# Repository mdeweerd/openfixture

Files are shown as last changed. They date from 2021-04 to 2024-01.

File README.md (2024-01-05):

# OpenFixture





## Goal

The motivation of OpenFixture was to make a parametric fixturing system
that could take fully generated inputs from kicad and produce a test
fixture with minimal effort. The easiest way to use it is through the kicad
python scripting interface.

The project has been extended with Test PCB Schematic generation - you may
want to generate only that without building the proposed fixture.

## Parameters

For most projects (if using the standard BOM) the only parameters you'll
need to set are mat_th and pcb_th. Something like the following should be
sufficient:

```
usage: GenFixture.py [-h] --board BOARD --mat_th MAT_TH --out OUT
                     [--pcb_th PCB_TH] [--pcb_h PCB_H] [--screw_len SCREW_LEN]
                     [--screw_d SCREW_D] [--layer LAYER] [--flayer FLAYER]
                     [--ilayer ILAYER] [--rev REV] [--pogo_d POGO_D]
                     [--washer_th WASHER_TH] [--nut_f2f NUT_F2F]
                     [--nut_c2c NUT_C2C] [--nut_th NUT_TH] [--pivot_d PIVOT_D]
                     [--border BORDER] [--render] [--kicad]
                     [--annular ANNULAR] [--logo LOGO] [--logo-w LOGO_W]
                     [--logo-h LOGO_H] [--pins PINS]
                     [--exclude-size EXCLUDE_SIZE]

optional arguments:
  -h, --help            show this help message and exit
  --board BOARD         <board_name.kicad_pcb>
  --mat_th MAT_TH       material thickness (mm)
  --out OUT             output directory
  --pcb_th PCB_TH       pcb thickness (mm)
  --pcb_h PCB_H         pcb component height (mm)
  --screw_len SCREW_LEN
                        Assembly screw thread length (default = 16mm)
  --screw_d SCREW_D     Assembly screw diameter (default=3mm)
  --layer LAYER         F.Cu | B.Cu
  --flayer FLAYER       Eco1.User | Eco2.User
  --ilayer ILAYER       Eco1.User | Eco2.User
  --rev REV             Override revision
  --pogo_d POGO_D       Pogo hole diameter (default=1.22mm)
  --washer_th WASHER_TH
                        Washer thickness for hinge
  --nut_f2f NUT_F2F     hex nut flat to flat (mm)
  --nut_c2c NUT_C2C     hex nut corner to corner (mm)
  --nut_th NUT_TH       hex nut thickness (mm)
  --pivot_d PIVOT_D     Pivot diameter (mm)
  --border BORDER       Board (ledge) under pcb (mm)
  --render              Generate a 3d render of the final fixture
  --kicad               Generate a KiCad project
  --annular ANNULAR     Annular ring width for PADS on PCB
  --logo LOGO           Override logo
  --logo-w LOGO_W       Set logo width, mm
  --logo-h LOGO_H       Set logo height, mm
  --pins PINS           Extra pins to include (THT/SMD) REF-PINNBR - comma
                        separated
  --exclude-size EXCLUDE_SIZE
                        Module refs to exclude from board size - comma
                        separated
```

The resulting output is:

- A 3D model of the test fixture for visualization (optional, with
  '--render')
- 2D DXF files that can be directly lasercut for assembly (several
  organisations)
- A kicad project for a test board (optional)

## Requirements

- Setup your path to run KiCad's python (or a python with pcbnew).
- You may need to install some modules.\
  Either to your personal directory
  (example for ezdxf module, required for KiCad
  generation):\
  `pip install --user ezdxf`\
  Either
  globally:\
  `pip install ezdxf`

## Recommended workflow for KiCad

1. Clone this repo if you haven't already
2. Setup a project specific bash script (use genfixture.sh as an example),
   and/or add a `fixture.conf` file to your project.
3. Enter board specific info, fixture hardware, material thickness, etc.
4. Whenever the layout changes call ./genfixture.sh (from repo) and pass
   path to .kicad_pcb file.
5. Fixture will be generated in $OUTPUT folder.

## Helper script

`genfixture.sh` is a helper script that you can call with just the path to
the PROJET.kicad_pcb file. You can add more options which will be appended
to the call to `GenFixture.py`.

On windows, that script can be used under cygwin. The `cygwin.setpath`
include script shows how you can set the system paths.

`genfixture.sh` also checks the directory where the project file is located
for a `fixture.conf` configuration file and includes the contents of that
file as a bash include script.

## Hints

- Examine the `genfixture.sh` helper script to learn about option.
- If you want smaller pogo pin holes for the test fixture than the PCB,
  perform multiple generations with different parameters.

## KiCAD Test Schematic & Board Generation

The `generate_kicad.py` script is called from `GenFixture.py` when the
`--kicad` option is added.

This generates a schematic sheet with the test pins connected to global
netnames corresponding to the netnames on the original schematic. It also
generates a board that puts the test pins in the right locations.

You can edit the board to change the EDGES to make a bigger board for
instance. You can edit the schematic to add other connectors for test
purposes or electronics for test purposes.

The best method would be the use of hierarchical sheets so that the POGOPIN
schematic can be regenerated.

## Hardware

- All that is needed is 14xM3 (14mm+) screws, 14xM3 hex nuts, and lasercut
  parts
- Nylon bushings in the main pivot with m3 screws for a smoother joint can
  be used, but this is optional

## Documentation

https://tinylabs.io/openfixture

## BOM

Material needed to build the Fixture: https://tinylabs.io/openfixture-bom

- 15 M3 nuts
- 15 M3 hex nuts
- Pogo sockets
- Pogo pins
- Glue

Pogo pins come in different sizes, and are composed of a socket and a pin.
There are R100 sockets, as well as R50 sockets and other sized. The drill
sizes change accordingly. You can find them from different sources. You can
find several source by looking for `R100-2S` or `R50-2W7`

- DirtyPCBs proposes R100-\* type sockets. Make sure that you use the
  corresponding P100-\* pins
  https://dirtypcbs.com/store/designer/details/ian/12/dirty-pogo-pins
- Aliexpress, Alibaba, Amazon, CDiscount are marketplaces where you can
  find many other vendors.

## STEP export

A standalone scad file is generated.\
Copy the logos and font to the
directory where the generated scad file is located. Or, copy the SCAD file
to the script directory. You can perform
`./convert_shape.py <SCADFILE> out.step` to convert to STEP for instance.

There is a bug in FreeCad 0.19 that prevents generation (on Windows)

## STL export

A standalone scad file is generated.\
Copy the logos and font to the
directory where the generated scad file is located. Or, copy the SCAD file
to the script directory. You can perform
`openscad --render -o out.stl <SCADFILE>` to convert to STL for instance.

## Testpoint validation

To verify that all your testpoints are within the PCB area, you can check
that no checkpoint appears in the `*-validate.dxf` file.

## Assembly

More info including detailed assembly instructions at
https://tinylabs.io/openfixture-assembly

## Dependencies

- Newer version of openscad >= 2015.03-1
- kicad or other EDA software. Please email me if you have instructions for
  other packages so I can add them.

## Known Issues

- When loading the fonts file a new small window opens in Ubuntu. Seems
  innocuous but still annoying \[Only seen on ubuntu 14.04\]
- STEP generation with FreeCAD is not entirely functional

## License

Creative Commons (CC BY-SA 4.0)

## Contributors

- Elliot Buller - Tiny Labs Inc
- Mario DE WEERD - Ynamics

(?) Please email with any pull requests or new feature requests
elliot@tinylabs.io

## Resources

KiCAD PCB generation script initiated from
https://github.com/jaseg/pogojig.git

## Work in progress / possible features

- The generation of a hierchical sheet is work in progress
- 3D models of test sockets and pins are generated. They must be verified
  and could be integrated as KiCad components.
- Mechanical holes should also be "exported" to the KiCad project to allow
  adding guides.
- Add a filter to exclude specific pins.
- KiCad integration (in a distant future)

# Old stuff

## KiCAD export

https://tinylabs.io/openfixture-kicad-export

Getting the test pins from the kicad schematic is integrated in this
project.

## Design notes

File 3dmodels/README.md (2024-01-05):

# Pin 3D Models

Most Pogo Pin models are generated using the `create-steps.sh` script that
calls upon the `pogopins.scad` script. At this time they are not verified
against physical pins so measures may be incorrect.

There are other 3D Models available on the Web that are not provided in
this repository. They can be downloaded from the following sources and are
subject to their respective licences.

- https://grabcad.com/library/pogo-pins-1

# Actual Pogo-pins

- After inserting the P50-J1 pin in the R50-2W7 socket, the total extended
  length is about 21mm. The non moving part of the pin enters entirely in
  the socket. The moving part of the pin extends about 3.5mm from the end
  and retracts fully when pushed.\
  The R-50-2W7 is 13mm in length from the
  pin entry up to the retraction before the wire.\
  The Wire entry up to the
  retraction is 4.5mm, the total length of the socket is 17.5mm The
  extrusion on the R50-2W7 socket is 2.5mm from the edge

# TODO

- Add more pin heads;
- Also generate "compressed" versions of the PIN Models (i.e., versions
  where the pin extends less from the socket because it is compressed
  against a board).

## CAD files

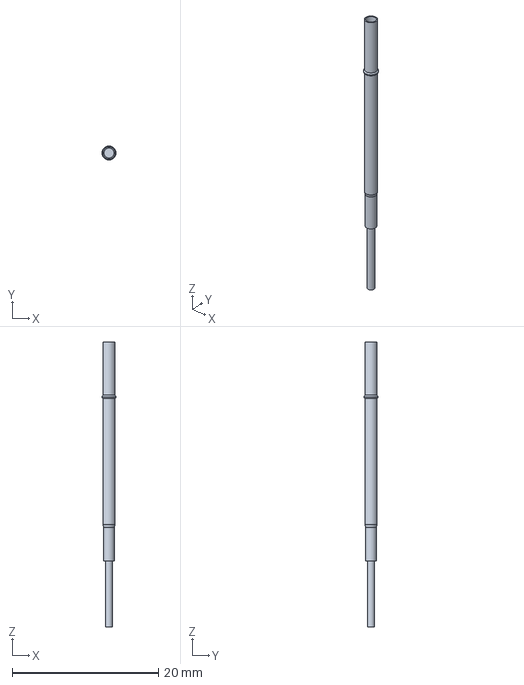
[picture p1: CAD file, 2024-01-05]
3dmodels/tmp.step
1.93 x 1.93 x 39.0 mm

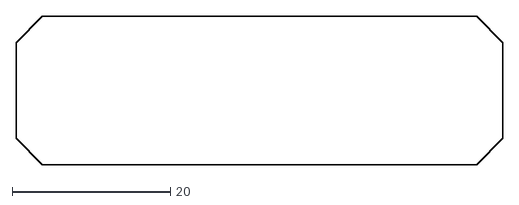
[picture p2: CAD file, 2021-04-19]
demo_result/yardstickone-validate.dxf
61.5 x 18.7

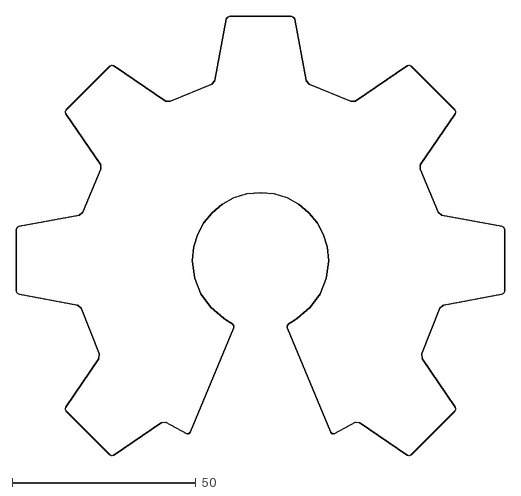
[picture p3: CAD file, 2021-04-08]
osh_logo.dxf
132.9 x 119.6

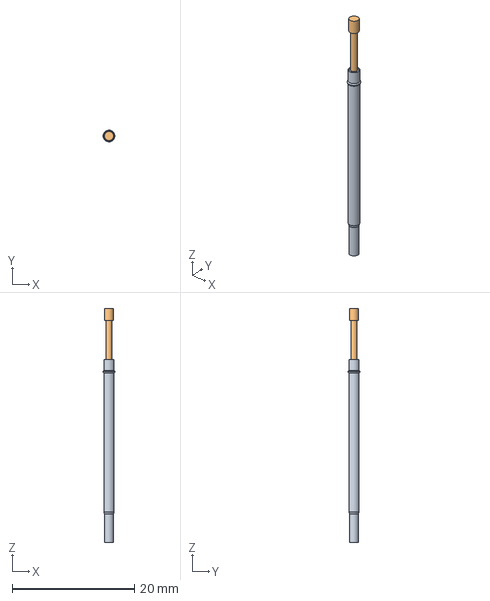
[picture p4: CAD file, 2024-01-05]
3dmodels/R100-2S-P100-G2.step
1.93 x 1.93 x 38.4 mm

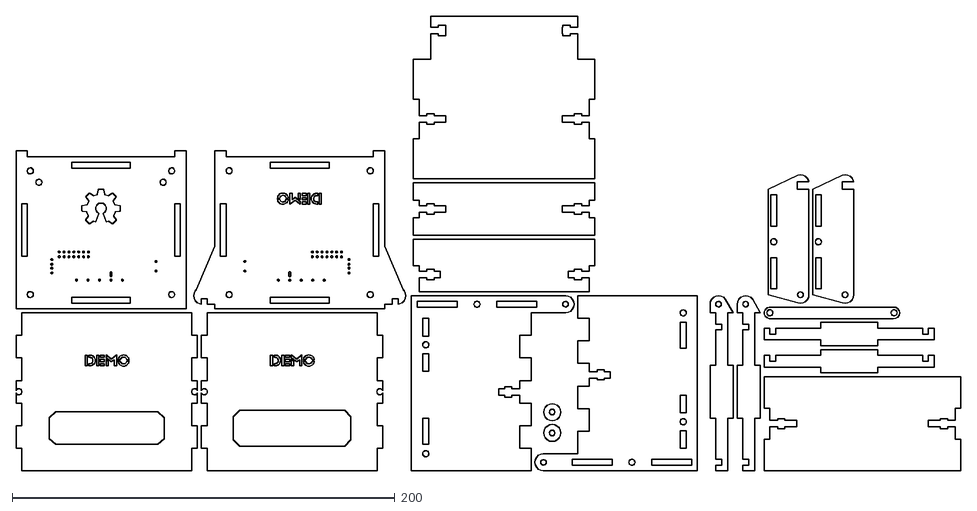
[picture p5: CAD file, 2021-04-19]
demo_result/yardstickone-v2-fixture.dxf
494.0 x 237.7

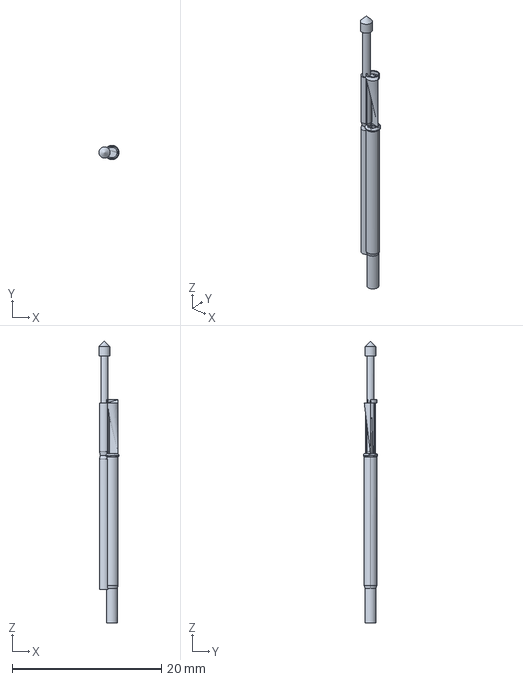
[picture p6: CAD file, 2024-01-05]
3dmodels/test.step
2.71 x 1.93 x 37.9 mm

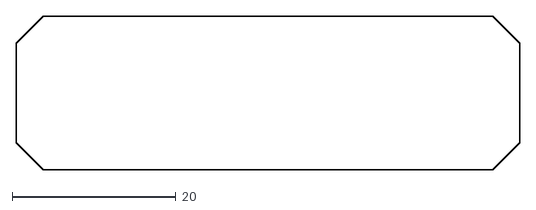
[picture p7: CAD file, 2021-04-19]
demo_result/yardstickone-outline.dxf
61.5 x 18.7

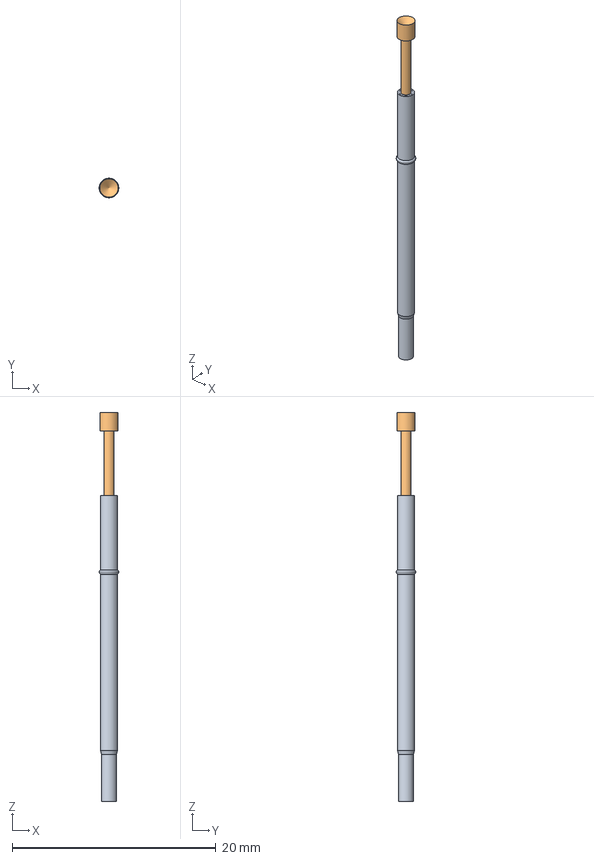
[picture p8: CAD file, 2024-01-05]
3dmodels/R100-4S-P100-A3.step
1.93 x 1.93 x 38.1 mm

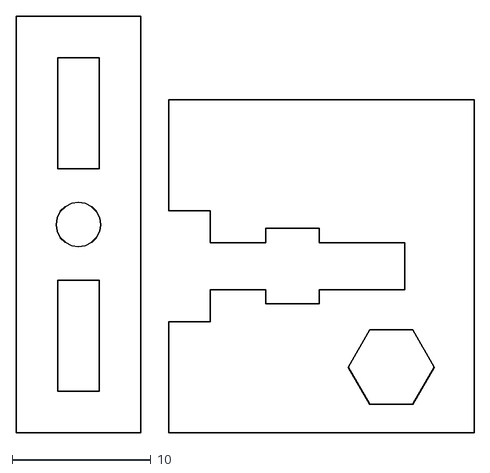
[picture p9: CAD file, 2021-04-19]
demo_result/yardstickone-test.dxf
33.0 x 30.0

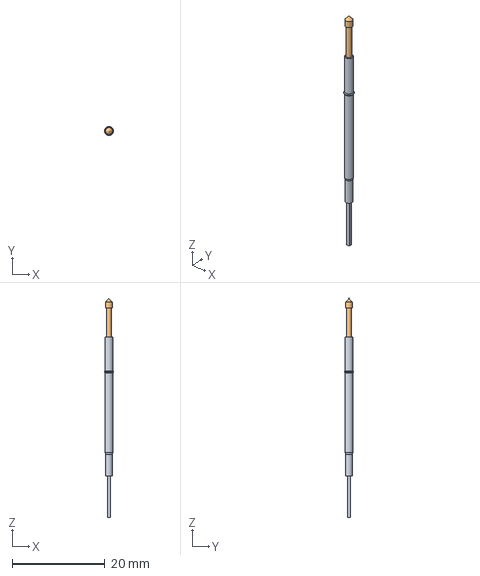
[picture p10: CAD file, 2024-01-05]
3dmodels/R100-4W-P100-E2.step
1.93 x 1.93 x 47.4 mm

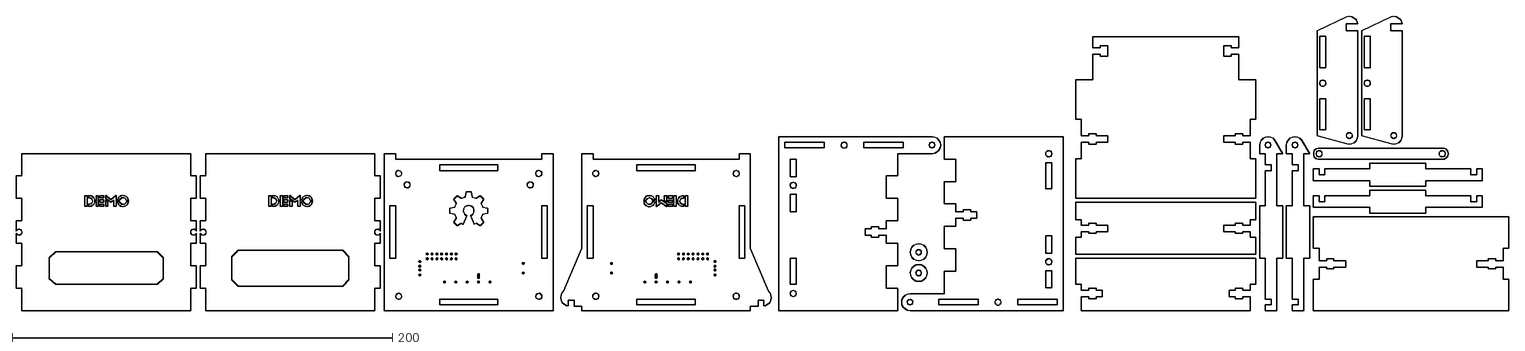
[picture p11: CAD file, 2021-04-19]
demo_result/yardstickone-fixture.dxf
785.6 x 154.8

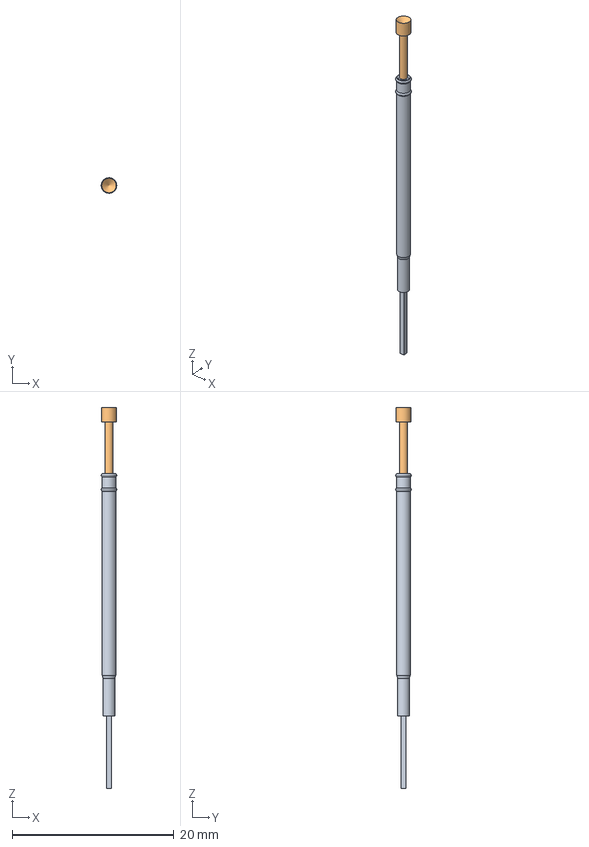
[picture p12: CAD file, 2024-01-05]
3dmodels/R100-1W-P100-A3.step
1.93 x 1.93 x 47.1 mm

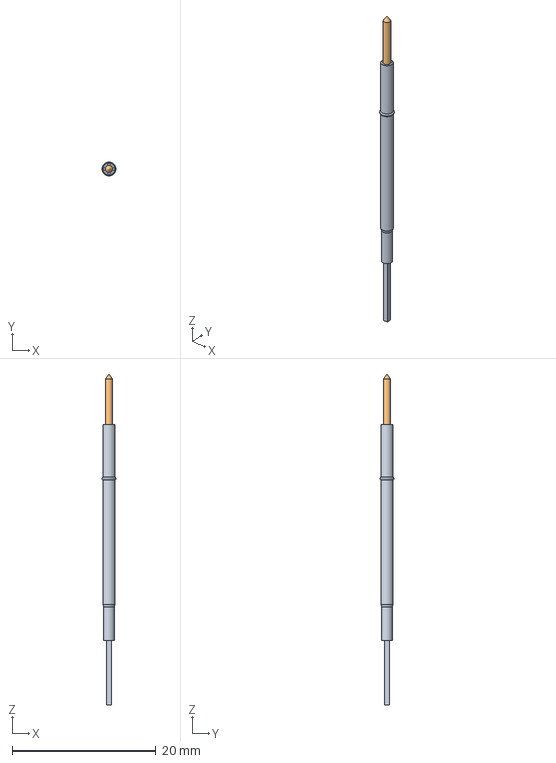
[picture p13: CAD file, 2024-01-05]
3dmodels/R100-4W-P100-B1.step
1.93 x 1.93 x 46.1 mm

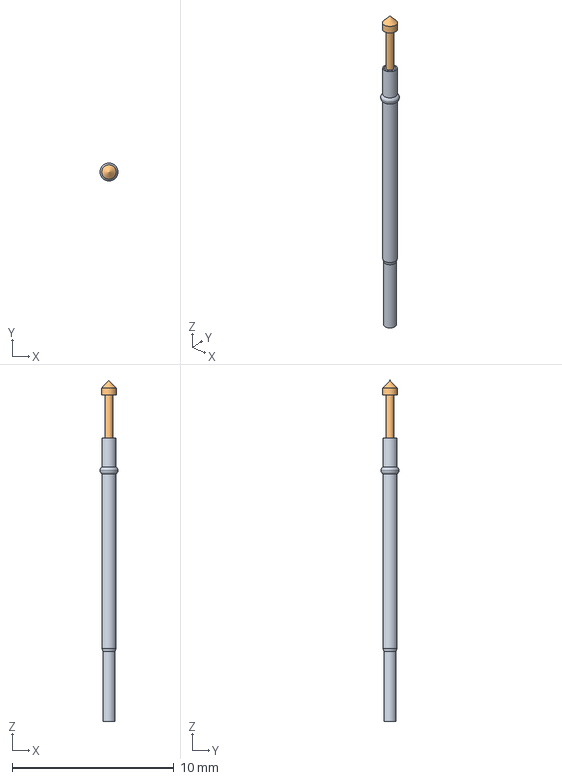
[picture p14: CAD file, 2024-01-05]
3dmodels/R50-2W7-P50-E2.step
1.11 x 1.11 x 21.0 mm

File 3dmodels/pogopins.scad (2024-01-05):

/**
 * Author: Mario DE WEERD - https://github.com/mdeweerd
 *
 * License: CC-BY-SA
 *   See: by-sa-4.0.md or https://creativecommons.org/licenses/by-nc-sa/4.0/legalcode
 */
// This script generates POGOPIN models.
// Note: The result has not been compared with physical pins yet.
gold="#ffd700";

pin_type="B1";
//socket_type="1W";
//socket_type="2W";
socket_type="2W7";
//socket_type="4W";
//socket_type="5W";
//socket_type="2S";
//socket_type="4S";
//socket_type="4VW";
//socket_type="3T";
//family="R100";
family="R50";

pin_corps_d=(family=="R100")?1.36:
              (
               (family=="R50")?0.68:
                  -1
              );
pin_notch_off=(family=="R100")?7:
              (
               (family=="R50")?5: // Estimate
                  -1
              );
pin_corps_len=(family=="R100")?25:
              (
               (family=="R50")?13:
                  -1
              );


pin_head_diameter=((family=="R100")?1:((family=="R50")?0.48:-1));
pin_head_margin=0.02;
pin_corps_empty_diameter=pin_head_diameter+pin_head_margin;

pin_center_barrel_offset=10;
pin_center_barrel_ext_len=
          family=="R100"?6.35:
          (family=="R50"?2.65 // 2.65=average? - 3.5 measured
          :-1);
pin_center_barrel_len=pin_corps_len-pin_center_barrel_offset+pin_center_barrel_ext_len;

module pin_head() {

  // Pin outer cylinder
  difference() {
    cylinder(h=pin_corps_len,d=pin_corps_d,$fa=1,$fs=0.01,$fn=100);
    union() {
      // Remove center of cylinder
      translate([0,0,1]) // Bottom of 1mm
        cylinder(h=pin_corps_len,d=pin_corps_empty_diameter,$fa=1,$fs=0.01,$fn=100);
      if(0) // No notch was observed on the P50 pin type, disabling this.
      // Create "notch" in cylinder
      translate([0,0,pin_corps_len-pin_notch_off])
        difference() {
          translate([0,0,-0.5])
            cylinder(h=1,d=pin_corps_d,$fa=1,$fs=0.01,$fn=100);
          union() {
            cylinder(h=0.5,d2=pin_corps_d,d1=pin_corps_d*.85,$fa=1,$fs=0.01,$fn=100);
            mirror([0,0,1])
              cylinder(h=0.5,d2=pin_corps_d,d1=pin_corps_d*.85,$fa=1,$fs=0.01,$fn=100);
          }
        }
    }
  }


  translate([0,0,pin_center_barrel_offset])
    cylinder(h=pin_center_barrel_len,d=pin_head_diameter,$fa=1,$fs=0.01,$fn=100,center=false);

  pin_top_offset=pin_center_barrel_offset+pin_center_barrel_len;

  pin_top_diam=
    (family=="R100")?(
     (pin_type=="E2"||pin_type=="A2"||pin_type=="D2"||pin_type=="G2"||pin_type=="H2"||pin_type=="LM2"||pin_type=="Q2"||pin_type=="T2"||pin_type=="M3")
     ?1.5
    :(pin_type=="A3"||pin_type=="E3"||pin_type=="D3"||pin_type=="H3")
     ?1.8
     :(pin_type=="B1")
     ?0.99
     :(pin_type=="F1"||pin_type=="J1"||pin_type=="Q1"||pin_type=="G1")
     ?1.0
     :(pin_type=="H4")
     ?2.0
     :(pin_type=="H5")
     ?2.5
     :(pin_type=="H6")
     ?3.0
     :-1) // Invalid
   :
    (family=="R50")?
     (
      (pin_type=="E2"||pin_type=="A2"||pin_type=="D2"||pin_type=="E2"||pin_type=="G2"||pin_type=="H2"||pin_type=="LM2"||pin_type=="Q2"||pin_type=="T2")
     ?0.9 // 2
     :(pin_type=="B1"||pin_type=="F1"||pin_type=="F"||pin_type=="J1"||pin_type=="Q1"||pin_type=="G1")
      ?0.48 // 1
      :(pin_type=="E3"||pin_type==H3)
      ?1.20 // 3
      :(pin_type=="1D"||pin_type=="1E")
      ?0.6
     :-1 // Invalid
    ):-1;
  pin_top_h=
    (family=="R100")?(
     (pin_type=="M3")
     ?7.0
     :2.0)
    :((family=="R50")?
        ((pin_type=="B1"||pin_type=="J1"||pin_type=="Q1"||pin_type=="G1")
         ?0.7:0.9)
      :-1)
  ;

  if(pin_type=="E2"||pin_type=="E3") {
      translate([0,0,pin_top_offset])
        intersection() {
          cylinder(h=pin_top_h,d=pin_top_diam,$fa=1,$fs=0.01,$fn=100,center=false);
          // 90° cone
          cylinder(h=pin_top_h,d1=pin_top_h*2,d2=0,$fa=1,$fs=0.01,$fn=100,center=false);
        };
  } else if(pin_type=="A2"||pin_type=="A3") {
echo(pin_top_diam);
      translate([0,0,pin_top_offset])
        difference() {
          cylinder(h=pin_top_h,d=pin_top_diam,$fa=1,$fs=0.01,$fn=100,center=false);
          translate([0,0,pin_top_h+pin_top_diam/2])
            mirror([0,0,1])
              cylinder(h=pin_top_h,d1=pin_top_h*2,d2=0,$fa=1,$fs=0.01,$fn=100,center=false);
        };
  } else if(pin_type=="G2"||pin_type=="G1") {
      translate([0,0,pin_top_offset])
        cylinder(h=pin_top_h,d=pin_top_diam,$fa=1,$fs=0.01,$fn=100,center=false);
  } else if(pin_type=="B1") {
      //color("red")
      translate([0,0,pin_top_offset])
        cylinder(h=pin_top_diam*cos(45),d2=0,d1=pin_top_diam,$fa=1,$fs=0.01,$fn=100,center=false);
  }
}


  cil_top_h=(family=="R100"?25:(family=="R50"?13:-1));
  ring_mid_d=(family=="R100"?1.83:(family=="R50"?0.95:-1));
  ring_top_d=(family=="R100"?1.9:(family=="R50"?0.98:-1));
  cil_top_d=(family=="R100"?1.68:(family=="R50"?0.86:-1));
  cil_mid_h=(family=="R100"?5:(family=="R50"?4.5:-1)); // Same for R100,R50
  cil_mid_d=(family=="R100"?1.47:(family=="R50"?0.75:-1));
  cub_bot_side=0.64;
  bot_d=1;

  mid_cone_h=cil_mid_d*2;

  ring_mid_off= // Ring offset from top
    (socket_type=="1W"||socket_type=="2W"||socket_type=="2S"||socket_type=="2W7"||socket_type=="1W7"||socket_type=="2C")
       ?2 // Changed to 2 as observed on 2W7 measurement (was: 2.5)
    :(socket_type=="3T"||socket_type=="3C"||socket_type=="3S")?5
    :(socket_type=="4W"||socket_type=="4S"||socket_type=="4VW")
       ?7.5
    :(socket_type=="5W"||socket_type=="2S")
    ?10
    :-1;

  square_bot=
    (socket_type=="1W"||socket_type=="2W"||socket_type=="4W"||socket_type=="5W");
  circ_bot=(socket_type=="4VW"||socket_type=="3T");
  bot_h=(socket_type=="3T")?4.5:9;

module socket() {
  difference() {
    union() {
//color("red")
      // Top part of socket
      translate([0,0,-cil_top_h])
        cylinder(h=cil_top_h,d=cil_top_d,$fa=1,$fs=0.01,$fn=100);
      translate([0,0,-cil_top_h-cil_mid_h])
        union() {
          cylinder(h=cil_mid_h,d=cil_mid_d,$fa=1,$fs=0.01,$fn=100);
          translate([0,0,cil_mid_h-mid_cone_h])
            cylinder(h=mid_cone_h,d1=0,d2=cil_top_d,$fa=1,$fs=0.01,$fn=100);
        }
      // Bottom, depending on type
      if(square_bot) {
        translate([-cub_bot_side/2,-cub_bot_side/2,-cil_top_h-cil_mid_h-bot_h])
          cube([cub_bot_side,cub_bot_side,bot_h]);
      }
      if(circ_bot) {
        translate([0,0,-cil_top_h-cil_mid_h-bot_h])
          cylinder(d=bot_d,h=bot_h,$fa=1,$fs=0.01,$fn=100);
      }
      if(socket_type=="1W") {
        translate([0,0,-0.5/2])
          ring(d=cil_top_d+0.5/2,D=0.5);
      }
      translate([0,0,-ring_mid_off])
        ring(d=cil_top_d+0.5/2,D=0.5);
    };
    // Remove center of cylinder - allow pin to enter completely
    translate([0,0,-pin_corps_len+0.001])
      cylinder(h=pin_corps_len+pin_head_margin,d=pin_corps_d+0.02,$fa=1,$fs=0.01,$fn=100);
  }

}

module ring(D = 1, d = 10,$fn=100,center=true)
{
  rotate_extrude(angle=360)
    translate([d/2 - D/2, 0])
      circle(d=D);
}

z_zero_offset=0.1;
color(gold)
union() {
  // Combine socket and pin.
  translate([0,0,cil_top_h+z_zero_offset])
    socket();
  // The notch offset was removed as it was no observed on the physical pin.
  //translate([0,0,z_zero_offset+cil_top_h-pin_corps_len+pin_notch_off-ring_mid_off])
  // The non-moving part of the pin enters entirely in the socket
  translate([0,0,z_zero_offset+cil_top_h-pin_corps_len])
    pin_head();
}

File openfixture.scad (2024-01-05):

/**
 *  OpenFixture - The goal is to have a turnkey pcb fixturing solution
 *  as long as you have access to a laser cutter or laser cutting service.
 *
 *  The input is:
 *   1. (x, y) work area that is >= pcb size
 *   2. (x, y) coordidates of test point centers
 *   3. dxf of pcb outline aligned with (0,0) on the top left.
 *   4. Material parameters: acrylic thickness, kerf, etc
 *
 *  The output is a dxf containing all the parts (minus M3 hardware)
 *  to assemble the fixture.
 *
 *  Creative Commons Licensed  (CC BY-SA 4.0)
 *  Tiny Labs
 *  2016
 */
use <glaser-stencil-d.ttf>;
FONTNAME = "Glaser Stencil D";

//
// PCB input
//
// Test points
demo_test_points = [[23.22,25.85],[19.72,22.28],[3.95,25.77],[7.52,22.27],[13.60,13.70],[13.55,18.70],[13.55,34.90],[13.60,29.90],[44.03,101.93],[110,110],[100,100],[60,60]];
// 68.72, 121.43

test_points = demo_test_points;

// Used below to calculate distance from hinge to nearest point based on min
// contact angle... Ideally we want it as close to 90 degrees as possible
// All you have to know is look through 'y' column above and set to lowest val
tp_min_y = 13.7;

// DXF outline of pcb
pcb_outline = "./rfid_fob-outline.dxf";
osh_logo = "./osh_logo.dxf";

logo = "";

// PCB revision
rev = "rev.0";

// Should be close to actual pcb dimensions... Used for support structure only so not critical
pcb_x = 54;
pcb_y = 117.45;
pcb_support_border = 1;

pcb_max_height_component = 12.5;

logo_w = 50;
logo_h = 50;

// Work area of PCB
// Must be >= PCB size
// If you make this as big as any of the PCBs you work
// with you could then reuse the base and just swap the
// head and carriers based on the pcb you're using.
work_area_x = pcb_x;
work_area_y = pcb_y;

// Thickness of pcb
pcb_th = 1.6;  // Standard PCB size

//
// End PCB input
//

// Correction offset
// These are final adjustments relative to the board carrier.
// Usually these aren't needed but can be used to tweak alignment
tp_correction_offset_x = 0.0;
tp_correction_offset_y = 0.0;

// Default mode (for debug)
mode="3dmodel";
render=1;



// Smoothness function for circles
$fn = 15;

// All measurements in mm
// Material parameters
mat_th = 3.0;

// Kerf adjustment
kerf = 0.125;

// Space between laser parts
laser_pad = 2;

// Screw radius (we want this tight to avoid play)
// This should work for M3 hardware
// Just the threads, not including head
// Should be no less than 12
screw_thr_len = 16;
screw_d = 3.0;
screw_r = screw_d / 2;

// Uncomment to use normal M3 screw for pivot
// We need pivot_d tight for precise alignment
pivot_d = screw_d - 0.1;
// Uncomment to use bushing in pivot
//pivot_d = 5.12;
pivot_r = pivot_d / 2;

// Pivot support, 3mm on either side
pivot_support_d = pivot_d + 6;
pivot_support_r = pivot_support_d / 2;

// Metric M3 hex nut dimensions
// f2f = flat to flat
nut_od_f2f = 5.45;
nut_od_c2c = 6;
nut_th = 2.25;

// Option to add nylon washer on latching mechanism for smoother
// operation - disabled by default
washer_th = 0;
//washer_th = 1;

// Pogo pin receptable dimensions
// I use the 2 part pogos with replaceable pins. Its a lifer save when a
// pin breaks. Undersized so they can be carefully drilled out using #50
// drill bit for better precision. If you have access to a nicer laser you
// can size these exactly
pogo_r = 1.22 / 2;

// Uncompressed length from receptacle
pogo_uncompressed_length = 16;
pogo_compression = 1;

// Locking tab parameters
tab_width = 3 * mat_th;
tab_length = 4 * mat_th + washer_th;

// Stop tab
stop_tab_y = 2 * mat_th;

// HANDLE_DO_NOT_REMOVE

//
// DO NOT EDIT BELOW... unless you feel like it ;-)
//
// Calculate min distance to hinge with a constraint on
// the angle of the pogo pin when it meets compression with the board.
// a = compression
// c = active_y_offset + pivot_support_r
// cos (min_angle) = a^2 / (2ca)
min_angle = 89.5;

// Calculate active_y_back_offset
active_y_back_offset = (pow (pogo_compression, 2) / (cos (min_angle) * 2 * pogo_compression)) - pivot_support_r - tp_min_y;

// Active area parameters
active_x_offset = 2 * mat_th + nut_od_f2f + 2;
active_y_offset = 2 * mat_th + nut_od_f2f + 2;

// Head dimensions
head_x = work_area_x + 2 * active_x_offset;
head_y = work_area_y + active_y_offset + active_y_back_offset;
head_z = screw_thr_len - nut_th;

// Base dimensions
base_x = head_x + 2 * mat_th;
base_y = head_y + pivot_support_d;
//base_z = screw_thr_len + 3 * mat_th;
base_z = screw_thr_len + 3 * mat_th + (pcb_max_height_component - 12.5);
base_pivot_offset = pivot_support_r +
                    (pogo_uncompressed_length - pogo_compression) -
                    (mat_th - pcb_th);

// To account for capture nut overhang
nut_pad = (nut_od_c2c - mat_th) / 2;

// Derived latch dimensions
latch_z_offset = (base_z * (2 / 3) + base_pivot_offset - pivot_r) / 2;
support_x = base_x / 12 + 2 * mat_th;
latch_support_y = base_z * (2 / 3) + base_pivot_offset - pivot_support_r - 2 * mat_th;



if (mode == "lasercut")  lasercut ();
if (mode == "lasercut_v2")  lasercut_v2 ();
if (mode == "3dmodel") 3d_model ();
if (mode == "validate") validate_testpoints (pcb_outline);
if (mode == "testcut") testcut ();

//
// MODULES
//
module tnut_female (n, length = screw_thr_len)
{
    // How much grip material
    tnut_grip = 4;

    // Pad for screw
    pad = 0.4;
    screw_len_pad = 1;

    // Screw hole
    translate ([0, -screw_r - pad/2])
      square ([length + screw_len_pad, screw_d + pad]);

    // Make space for nut
    translate ([mat_th * n + tnut_grip, -nut_od_f2f/2])
      square ([nut_th, nut_od_f2f]);
}

module tnut_hole ()
{
    pad = 0.1;
    circle (r = screw_r + pad, $fn = 20);
}

module tng_n (length, cnt)
{
    tng_y = (length / cnt);

    translate ([0, -length / 2])
      union () {
        for (i = [0 : 2 : cnt - 1]) {
            translate ([0, i * tng_y])
              square ([mat_th, tng_y]);
        }
      };
}

module tng_p (length, cnt)
{
    tng_y = length / cnt;

    translate ([0, -length / 2])
      union () {
        for (i = [1 : 2 : cnt - 1]) {
            translate ([0, i * tng_y])
              square ([mat_th, tng_y]);
        }
      };
}

module nut_hole ()
{
    pad = 0.05;
    circle (r = nut_od_c2c/2 + pad, $fn = 6);
}

module testcut ()
{
    y = 30;
    off = 3 * mat_th + laser_pad;

    difference () {
        union () {
            square ([3 * mat_th, y]);

            translate ([off, 0])
              square ([screw_thr_len + 2 * mat_th, y - 2 * mat_th]);
        }
        // Remove tng slot
        translate ([mat_th, y/2])
          tng_n (y - 2 * mat_th, 3);

        // Remove tnut hole
        translate ([mat_th * 3/2, y/2])
          tnut_hole ();

        // Remove tng from male side
        translate ([off, y/2 - mat_th])
          tng_p (y - 2 * mat_th, 3);

        // Remove tnut
        translate ([off, y/2 - mat_th])
          tnut_female (1);

        // Remove nut hole
        translate ([off + nut_od_c2c / 2 + screw_thr_len - mat_th, nut_od_f2f / 2 + 2])
          nut_hole ();
    }
}

module head_side ()
{
    x = head_z;
    y = head_y;
    r = pivot_support_r;

    difference () {
        union () {
            hull () {
                translate ([0, y])
                  square ([x, 0.01]);

                // Add pivot point
                translate ([r, y + pivot_support_r])
                  circle (r = pivot_support_r, $fn = 20);
            };
            square ([x, y]);
        }

        // Remove pivot
        translate ([r, y + r])
          circle (r = pivot_r, $fn = 20);

        // Remove slots
        translate ([0, y / 2])
          tng_n (y, 3);
        translate ([x - mat_th, y / 2])
          tng_n (y, 3);

        // Remove lincoln log slots
        translate ([0, mat_th])
          square ([x / 2, mat_th]);
        translate ([0, y - 3 * mat_th])
          square ([x / 2, mat_th]);
    }
}

module head_front_back ()
{
    x = head_x;
    y = head_z;

    difference () {
        square ([x, y]);

        // Remove grooves
        translate ([x / 2, 0])
          rotate ([0, 0, 90])
            tng_n (x, 3);
        translate ([x / 2, y - mat_th])
          rotate ([0, 0, 90])
            tng_n (x, 3);

        // Remove assembly slots
        translate ([mat_th, y / 2])
          square ([mat_th, y / 2]);
        translate ([x - 2 * mat_th, y / 2])
          square ([mat_th, y / 2]);
    }
}

module lock_tab ()
{
    translate ([-tab_length/2, 0])
      square ([tab_length, tab_width]);
    translate ([-tab_length/2, tab_width/2])
      circle (r = tab_width / 2, $fn = 20);
    translate([0, tab_width / 2])
      polygon([[0,0], [-tab_length/2 - tab_width /2, 0], [0,tab_length * 2], [0,0]]);
}

module head_base ()
{
    nut_offset = 2 * mat_th + screw_r;

    difference () {

        union () {
            // Common base
            head_base_common ();
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

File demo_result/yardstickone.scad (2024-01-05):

/**
 *  OpenFixture - The goal is to have a turnkey pcb fixturing solution
 *  as long as you have access to a laser cutter or laser cutting service.
 *
 *  The input is:
 *   1. (x, y) work area that is >= pcb size
 *   2. (x, y) coordidates of test point centers
 *   3. dxf of pcb outline aligned with (0,0) on the top left.
 *   4. Material parameters: acrylic thickness, kerf, etc
 *
 *  The output is a dxf containing all the parts (minus M3 hardware)
 *  to assemble the fixture.
 *
 *  Creative Commons Licensed  (CC BY-SA 4.0)
 *  Tiny Labs
 *  2016
 */
use <glaser-stencil-d.ttf>;
FONTNAME = "Glaser Stencil D";

//
// PCB input
//
// Test points
demo_test_points = [[23.22,25.85],[19.72,22.28],[3.95,25.77],[7.52,22.27],[13.60,13.70],[13.55,18.70],[13.55,34.90],[13.60,29.90],[44.03,101.93],[110,110],[100,100],[60,60]];
// 68.72, 121.43

test_points = demo_test_points;

// Used below to calculate distance from hinge to nearest point based on min
// contact angle... Ideally we want it as close to 90 degrees as possible
// All you have to know is look through 'y' column above and set to lowest val
tp_min_y = 13.7;

// DXF outline of pcb
pcb_outline = "./rfid_fob-outline.dxf";
osh_logo = "./osh_logo.dxf";

logo = "";

// PCB revision
rev = "rev.0";

// Should be close to actual pcb dimensions... Used for support structure only so not critical
pcb_x = 54;
pcb_y = 117.45;
pcb_support_border = 1;

pcb_max_height_component = 12.5;

logo_w = 50;
logo_h = 50;

// Work area of PCB
// Must be >= PCB size
// If you make this as big as any of the PCBs you work
// with you could then reuse the base and just swap the
// head and carriers based on the pcb you're using.
work_area_x = pcb_x;
work_area_y = pcb_y;

// Thickness of pcb
pcb_th = 1.6;  // Standard PCB size

//
// End PCB input
//

// Correction offset
// These are final adjustments relative to the board carrier.
// Usually these aren't needed but can be used to tweak alignment
tp_correction_offset_x = 0.0;
tp_correction_offset_y = 0.0;

// Default mode (for debug)
mode="3dmodel";
render=1;



// Smothness function for circles
$fn = 15;

// All measurements in mm
// Material parameters
mat_th = 3.0;

// Kerf adjustment
kerf = 0.125;

// Space between laser parts
laser_pad = 2;

// Screw radius (we want this tight to avoid play)
// This should work for M3 hardware
// Just the threads, not including head
// Should be no less than 12
screw_thr_len = 16;
screw_d = 3.0;
screw_r = screw_d / 2;

// Uncomment to use normal M3 screw for pivot
// We need pivot_d tight for precise alignment
pivot_d = screw_d - 0.1;
// Uncomment to use bushing in pivot
//pivot_d = 5.12;
pivot_r = pivot_d / 2;

// Pivot support, 3mm on either side
pivot_support_d = pivot_d + 6;
pivot_support_r = pivot_support_d / 2;

// Metric M3 hex nut dimensions
// f2f = flat to flat
nut_od_f2f = 5.45;
nut_od_c2c = 6;
nut_th = 2.25;

// Option to add nylon washer on latching mechanism for smoother
// operation - disabled by default
washer_th = 0;
//washer_th = 1;

// Pogo pin receptable dimensions
// I use the 2 part pogos with replaceable pins. Its a lifer save when a
// pin breaks. Undersized so they can be carefully drilled out using #50
// drill bit for better precision. If you have access to a nicer laser you
// can size these exactly
pogo_r = 1.22 / 2;

// Uncompressed length from receptacle
pogo_uncompressed_length = 16;
pogo_compression = 1;

// Locking tab parameters
tab_width = 3 * mat_th;
tab_length = 4 * mat_th + washer_th;

// Stop tab
stop_tab_y = 2 * mat_th;

//
// Parameters from command line
//
pogo_r = 0.45;
logo_h = 50;
nut_od_f2f = 5.45;
test_points = [[5.25,6.04],[5.25,8.54],[5.25,10.54],[5.25,13.04],[24.38,4.59],[24.38,2.05],[21.84,4.59],[21.84,2.05],[19.30,4.59],[19.30,2.05],[16.76,4.59],[16.76,2.05],[14.22,4.59],[14.22,2.05],[11.68,4.59],[11.68,2.05],[9.14,4.59],[9.14,2.05],[59.69,12.08],[59.69,7.00],[18.18,16.82],[24.19,16.82],[30.19,16.82],[36.19,16.82],[42.18,16.82],[36.19,14.49],[36.19,12.97],[36.19,13.73],];
nut_th = 3.85;
pcb_outline = "D:\\mdeweerd\\KiCAD\\openfixture\\demo_result\\yardstickone-outline.dxf";
logo_w = 50;
pcb_support_border = 0.80;
pcb_x = 61.97;
rev = "DEMO";
tp_min_y = 2.05;
nut_od_c2c = 6.10;
screw_thr_len = 16.00;
pcb_th = 1.60;
pcb_max_height_component = 50.00;
pcb_y = 18.40;
mat_th = 3.00;
screw_d = 3.00;
border = 0.80;
washer_th = 1.00;
mode = "3dmodel";


//
// DO NOT EDIT BELOW... unless you feel like it ;-)
//
// Calculate min distance to hinge with a constraint on
// the angle of the pogo pin when it meets compression with the board.
// a = compression
// c = active_y_offset + pivot_support_r
// cos (min_angle) = a^2 / (2ca)
min_angle = 89.5;

// Calculate active_y_back_offset
active_y_back_offset = (pow (pogo_compression, 2) / (cos (min_angle) * 2 * pogo_compression)) - pivot_support_r - tp_min_y;

// Active area parameters
active_x_offset = 2 * mat_th + nut_od_f2f + 2;
active_y_offset = 2 * mat_th + nut_od_f2f + 2;

// Head dimensions
head_x = work_area_x + 2 * active_x_offset;
head_y = work_area_y + active_y_offset + active_y_back_offset;
head_z = screw_thr_len - nut_th;

// Base dimensions
base_x = head_x + 2 * mat_th;
base_y = head_y + pivot_support_d;
//base_z = screw_thr_len + 3 * mat_th;
base_z = screw_thr_len + 3 * mat_th + (pcb_max_height_component - 12.5);
base_pivot_offset = pivot_support_r +
                    (pogo_uncompressed_length - pogo_compression) -
                    (mat_th - pcb_th);

// To account for capture nut overhang
nut_pad = (nut_od_c2c - mat_th) / 2;

// Derived latch dimensions
latch_z_offset = (base_z * (2 / 3) + base_pivot_offset - pivot_r) / 2;
support_x = base_x / 12 + 2 * mat_th;
latch_support_y = base_z * (2 / 3) + base_pivot_offset - pivot_support_r - 2 * mat_th;



if (mode == "lasercut")  lasercut ();
if (mode == "lasercut_v2")  lasercut_v2 ();
if (mode == "3dmodel") 3d_model ();
if (mode == "validate") validate_testpoints (pcb_outline);
if (mode == "testcut") testcut ();

//
// MODULES
//
module tnut_female (n, length = screw_thr_len)
{
    // How much grip material
    tnut_grip = 4;

    // Pad for screw
    pad = 0.4;
    screw_len_pad = 1;

    // Screw hole
    translate ([0, -screw_r - pad/2])
      square ([length + screw_len_pad, screw_d + pad]);

    // Make space for nut
    translate ([mat_th * n + tnut_grip, -nut_od_f2f/2])
      square ([nut_th, nut_od_f2f]);
}

module tnut_hole ()
{
    pad = 0.1;
    circle (r = screw_r + pad, $fn = 20);
}

module tng_n (length, cnt)
{
    tng_y = (length / cnt);

    translate ([0, -length / 2])
      union () {
        for (i = [0 : 2 : cnt - 1]) {
            translate ([0, i * tng_y])
              square ([mat_th, tng_y]);
        }
      };
}

module tng_p (length, cnt)
{
    tng_y = length / cnt;

    translate ([0, -length / 2])
      union () {
        for (i = [1 : 2 : cnt - 1]) {
            translate ([0, i * tng_y])
              square ([mat_th, tng_y]);
        }
      };
}
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

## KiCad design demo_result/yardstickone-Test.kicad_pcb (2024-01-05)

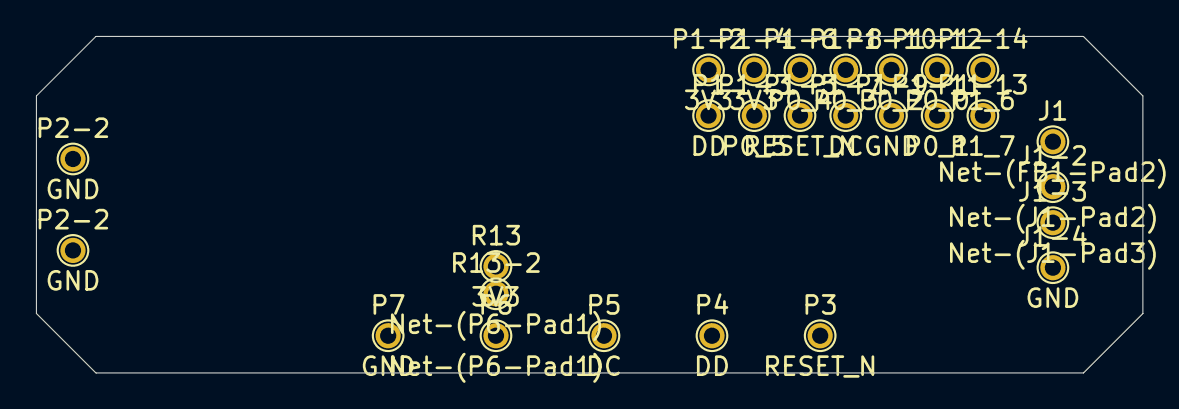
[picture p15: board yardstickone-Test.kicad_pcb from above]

Board: 2 copper layers, 61.5 x 18.7 mm, 27 parts (0 on the bottom side), 6 nets, no tracks yet.

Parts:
J1: pogo pin 0; None
J1-2: pogo pin 1; None
J1-3: pogo pin 2; None
J1-4: pogo pin 3; None
P1: pogo pin 4; None
P1-2: pogo pin 5; None
P1-3: pogo pin 6; None
P1-4: pogo pin 7; None
P1-5: pogo pin 8; None
P1-6: pogo pin 9; None
P1-7: pogo pin 10; None
P1-8: pogo pin 11; None
P1-9: pogo pin 12; None
P1-10: pogo pin 13; None
P1-11: pogo pin 14; None
P1-12: pogo pin 15; None
P1-13: pogo pin 16; None
P1-14: pogo pin 17; None
P2-2: pogo pin 18; None
P2-2#2: pogo pin 19; None
P3: pogo pin 20; None
P4: pogo pin 21; None
P5: pogo pin 22; None
P6: pogo pin 23; None
P7: pogo pin 24; None
R13: pogo pin 26; None
R13-2: pogo pin 25; None

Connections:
3V3: P1-2.1, P1-4.1, R13.1
DC: P1-7.1, P5.1
DD: P1.1, P4.1
GND: J1-4.1, P1-9.1, P2-2.1, P2-2#2.1, P7.1
unnamed: P6.1, R13-2.1
RESET_N: P1-5.1, P3.1

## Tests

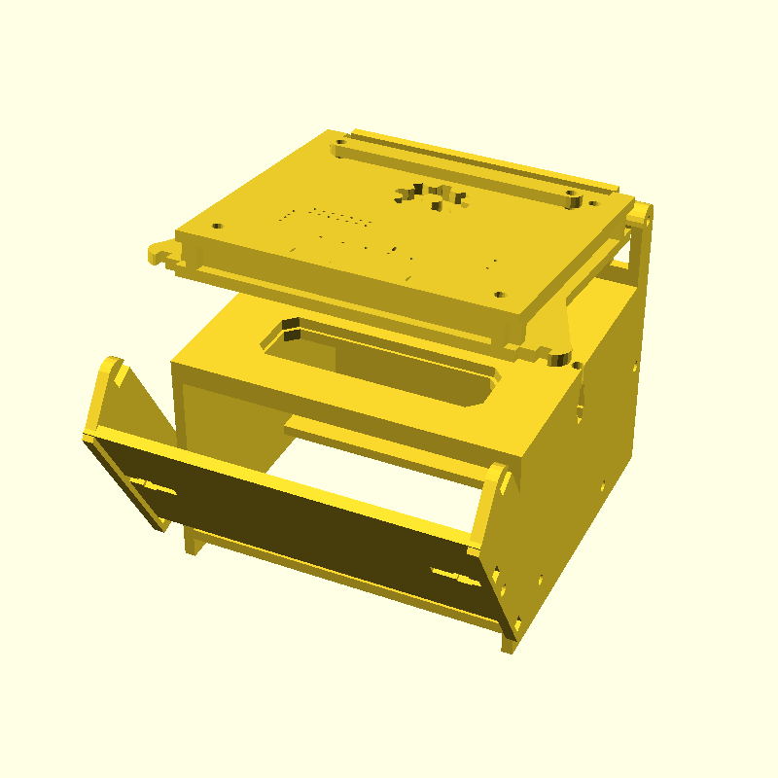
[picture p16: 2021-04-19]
demo_result/yardstickone-fixture.png

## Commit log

2017-12-03 Made all primitives 2D for peformance gains. Runs in less than 1 second now for a 2D render. 3D render performance is about 250% faster
    [openfixture.scad]
2017-12-05 beefed up tabs so they don't break so easily
    [openfixture.scad]
2017-12-12 fixed missing log cabin cut, fixed latch pivot hole being too far back
    [openfixture.scad]
2017-12-12 scad now uses logo w/h to center
    [openfixture.scad]
2017-12-12 logo now svg format
    [osh_logo.dxf]
2021-04-08 Removed printing commands
2021-04-08 Fixed logo option
    [osh_logo.dxf]
2021-04-08 Conditional logo dxf generation
    [osh_logo.dxf]
2021-04-08 Build mostly functionnal (repaired 3D construction)
    [openfixture.scad]
2021-04-09 Using 2D model for fixture generation
    [openfixture.scad]
2021-04-09 Printing TP information, not rendering 3D from wrapper, removed comment
    [openfixture.scad]
2021-04-09 Generate standalone scad file to allow STEP generation
    [openfixture.scad]
2021-04-09 Moved execution to later location (after parameter changes)
    [openfixture.scad]
2021-04-11 2nd logo import improved, fix issues related to PCB targets messing up size
    [openfixture.scad]
2021-04-11 Improved PCB outline management, option for pogo diameter, SVG for fixture, alternative layout
    [openfixture.scad]
2021-04-11 Removed leftover from verification of 3DMODEL
    [openfixture.scad]
2021-04-11 Enable max_height_component
    [openfixture.scad]
2021-04-11 Fixture v2 DXF generation offset correction, LAYER variable correction en genfixture, CLI quote correction
    [openfixture.scad]
2021-04-11 logo size & position corrected
    [openfixture.scad]
2021-04-13 Quote path to kicad python to cope with spaces.
2021-04-13 Add initial small library of test pin
2021-04-17 Add openscad model and pogopin model generation
    [pogopins.scad]
2021-04-17 Added more pogo pin models
    [R100-1W-P100-A2.step, R100-1W-P100-A3.step, R100-1W-P100-E2.step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]
2021-04-17 Added R50 & improved step comments
    [R100-1W-P100-A2.step, R100-1W-P100-A3.step, R100-1W-P100-E2.step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]
2021-04-18 More information in the files, correction to license label, improved shell script
    [R50-1S-P50-A2.step, R50-1S-P50-A3.step, R50-1S-P50-B1.step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]
2021-04-18 Netnames can be specified and are added to the schematic and pcb
2021-04-18 Complete kicad test pcb generation, annular ring, global labels, ...
2021-04-19 Added doDemo.sh demo script, documentation updates, added demo result
    [yardstickone-Test.kicad_pcb, yardstickone-Test.sch, yardstickone-fixture.dxf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]
2021-05-19 Updated steps after measuring R50-2W7 sockets and P50 pins
    [P058-Q1.step, P100-E2.step, P50-E1.step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]
2021-06-13 Add files via upload
    Add script to run it under Windows enviroment
    [openfixture.scad]
2021-11-24 Regenerated pins with color
    [R100-1W-P100-A2.step, R100-1W-P100-A3.step, R100-1W-P100-B1.step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]
2024-01-05 Add pre-commit flow & related adjustments
    [P058-Q1.step, P100-E2.step, P50-E1.step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]

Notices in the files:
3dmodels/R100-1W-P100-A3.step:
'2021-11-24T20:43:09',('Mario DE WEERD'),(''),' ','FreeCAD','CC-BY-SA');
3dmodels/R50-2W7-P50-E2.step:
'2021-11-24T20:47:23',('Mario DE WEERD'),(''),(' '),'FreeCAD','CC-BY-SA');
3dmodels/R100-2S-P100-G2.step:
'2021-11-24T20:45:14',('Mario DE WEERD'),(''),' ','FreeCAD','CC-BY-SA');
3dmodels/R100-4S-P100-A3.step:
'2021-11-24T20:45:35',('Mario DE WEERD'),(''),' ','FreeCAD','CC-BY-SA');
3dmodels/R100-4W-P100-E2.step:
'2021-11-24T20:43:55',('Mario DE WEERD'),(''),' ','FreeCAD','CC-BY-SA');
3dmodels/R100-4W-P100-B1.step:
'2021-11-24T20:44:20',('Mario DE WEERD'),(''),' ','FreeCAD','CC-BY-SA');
